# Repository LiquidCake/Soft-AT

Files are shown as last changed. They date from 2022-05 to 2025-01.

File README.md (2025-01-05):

# Soft-AT

This is an PC/AT (and PC/XT) compatible ISA board that provides some simple implementation of soft power controls (like we have on PC/ATX)  
Board should work on any PC with at least 8-bit ISA bus starting from original IBM-PC and up to Pentium machines  
Driver is tested on Windows 98 but probably may work on all Win9x  

### Functionality:
When properly installed & wired board allows power on/off for AT machine to mimic look&feel of power controls of ATX machine  
i.e. 
```
when PC is off - pressing (soft) power button starts it normally
when PC is on - pressing (soft) power button triggers windows shutdown and then poweroff after windows is unloaded (instead of instant hard poweroff of regular AT PSU)
when user clicks on shutdown in windows start menu - board receives signal and will turn power off after some delay (so windows will already be unloaded at that point)
```

**DISCLAIMER 1: this is a hobby project made by a person who is NOT and electronics engineer so it may be flawed in any possible way. It works though**

**DISCLAIMER 2: due to war i wasn't able to actually solder and test last revision of board, though it was just a minor tracks fix so should be fine**   

**For same reason i wasn't able to order and test board with actual 74LS series chips so it was tested only with 74LS's Soviet clones that i had easily available. They should be pretty much identical to original chips though**

**And this is also why there are no real pictures of assembled and properly installed board, only 3d renders**

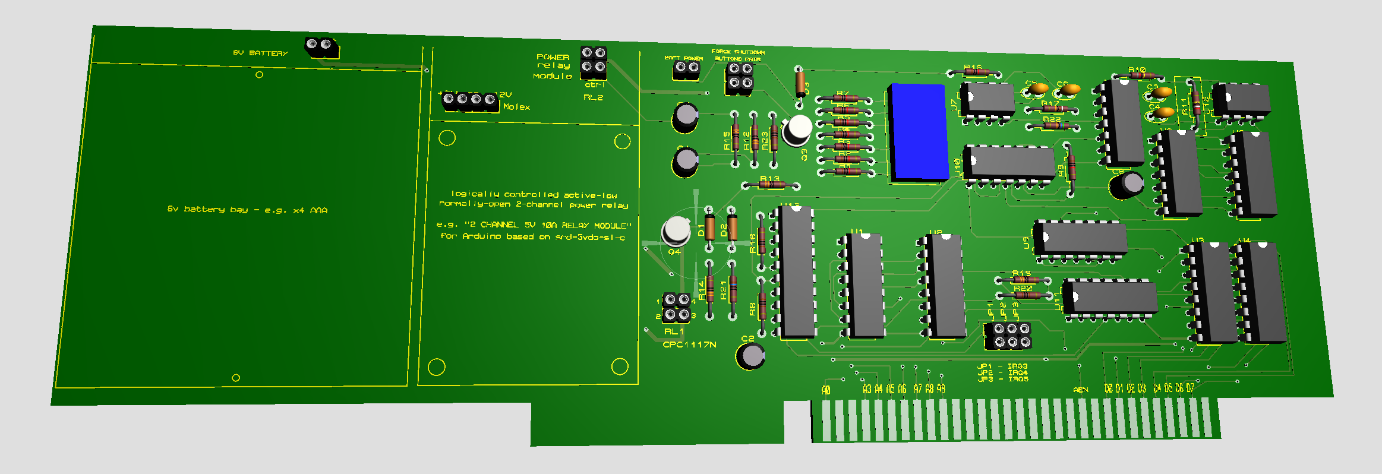
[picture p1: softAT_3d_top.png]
render


### Description:
Board was developed using `Proteus 8`, project files are provided as well as schematics and model screenshots  

In order to make board:  
- produce (order) PCB using provided `Gerber` files  
- mount/solder components from `components.txt` (the list is numerated list, same numbers on PCB silk and on schematics screenshot/Proteus project)  
*check component mount guide picture*
- insert board into ISA slot
- **!!!WARNING - high voltage here** disconnect your AT PSU from PC power switch (4 cables) and connect cables to large power relay RL2 that you've mounted on board  
DOUBLE CHECK:  
AT switch connects `white-to-blue`, `black-to-brown` so relay RL2 must do the same
- connect soft power button that will be used as PC power button  
(e.g. ideally you may put your AT motherboard and AT PSU into ATX PC case which has soft power button with proper header by default, though it is possible only if holes on board match ATX case board mount points)  
- probably connect reset button as force shutdown button `1` (see `force shutdown buttons` details below)
- connect one of PSU molex power connector to molex header on board (use smaller one, like one used for 3.5 floppies)  
- pick free IRQ and IO port address and set it on board phisically (check driver readme for more info on IRQ and IO port picking)  
	1. pick IRQ that is free on your PC and set it by board jumper `JP1/JP2/JP3` (e.g. `IRQ 3`)
	2. pick IO port that is free on your PC, convert its hex number to binary and set higher 7 bits by board DIP switch DSW1 (e.g. if using IO port address HEX `220` - convert to binary: `1000100000` and take 7 higher bits - `1000100`)
- adjust R11 so board timer ticks ~1sec at a time when counting for shutdown delay - e.g. set it to middle value and change a bit to find proper position empirically during device testing, having set driver shutdown delay to known value in seconds :)
- insert batteries into mounted battery bay (tested with `AA` batteries)  
make sure not to forget batteries inside bay for a long time because of possible leakage. Also for that reason it makes sense to use a very bottom ISA slot for vertical PC cases  
- install driver (.vxd and config) using install.bat (tested to work on Windows 98) - check readme for driver    

#####
Shutdown process wont be triggered after pressing soft power button if windows is in fullscreen dos mode (like dos game)  
(workaround to somehow make it work is possible, but would require both hardware and sofrware changes)

##### force shutdown buttons
There are 2 force shutdown buttons:  
`1` for shutting down operating PC (resets power relay RL2) - on PCB this button's contacts are top pair  
it would make sense to connect PC reset button as this one

`2` for disabling RL1 that initially opens pre-start battery power for RL2 - may be needed if PC didnt start after RL1 opened e.g. due wall power issues - on PCB this button's contacts are bottom pair  
it would make sense to connect some external button as this one, e.g. ideally mount such button on back pannel bar of ISA board

##### BTW
it is possible to use board as just external low-precision ISA timer that sends interrupt when done but this is not supported in current driver version since no real usage for that mode  
(if timeout value is sent to board using IO port with 0 at the end, e.g. 220 instead of 221 - board wont shutdown and will just send interrupt to CPU instead)

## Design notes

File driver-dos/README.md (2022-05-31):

## dos driver

This is an old dos "driver" for Soft-AT (actually its just an interrupt service routine, not a full format driver).  

*It should work but was not tested for some time*  

Should be working starting from 8088 CPU and dos 2.0  

settings like IO port, IRQ number, timer delay etc.s are hardcoded  

When `isr` is launched it loads itself into RAM and stays residential, waiting for interrupts. Once interrupt comes (from soft power button press) - driver sends shutdown signal to Soft-AT board and PC will be powered off after delay

`timer` binary may be used to send signal to Soft-AT board manually

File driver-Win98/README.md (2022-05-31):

# driver config file
driver reads first 11 bytes of **C:\\softat.cfg** file (Three 3-digit hex numbers split by semi-colon). Format is strict - allways 3 digits (start from 0 if needed e.g. 07f)

e.g. 
```
--file starts
221;003;005
--file ends
```

## numbers meaning: 

### first - IO port 
e.g. you can set generally-free IO port "221". Then 220 must be  selected on board DIP switch, 1 means least significant bit is set which triggers shutdown mode.  

Used IO port may conflict with other devices IO address space! Make sure it is not assigned to other device and make it "reserved" in Windows Device Manager, "Computer" properties.  

If this port is assigned in Windows to other device - some values will be eventually written to this port which will lead to random shutdown request to SoftAT board  

### second - IRQ number 
IRQ3-IRQ5 are supported by board. Choose IRQ that is less probale to be used by other devices in system and put its number in config file, then set corresponding jumper on board (JP1 is IRQ3, JP2 is IRQ4, JP3 is IRQ5).  

*Attention: IRQ you chose may conflict with one of COM/PARALLEL ports!*  

Suggested value is 003 (IRQ3) - commonly used by COM2 port which could be easily disabled in BIOS (and then IRQ 3 is free to use)  

Also, this IRQ must be "reserved" in Windows Device Manager (in "Computer" properties)  

### third - shutdown delay in seconds (counts seconds after system exit event is received)
Value is in 1 byte hex (0-FF), so 0-255sec  
e.g. "005" is 5sec

# notes:
Driver wont catch interrupts (soft power button presses) when running fullscreen DOS app (like dos game) - you need to exit that first

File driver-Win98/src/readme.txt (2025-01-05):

How to build on Windows 98:

1. install C compiler - e.g. Visual CPP 5.00.7022
2. install VToolsD (NuMega) - e.g. SoftICE Driver Suite 2.0.1
	it should add itself to env variables which are used in make file for includes
	in case of issues - try specifying full path to nmake.exe inside make.bat 
	and check autoexec.bat file, possibly adding compiler/IDE/other required lib folders to system PATH variable etc
3. compile by running make.bat - i had to copy driver src files to VC compiler root folder (where bin, lib etc resides)
4. output is a softat.vxd file, build is logged to res.txt file

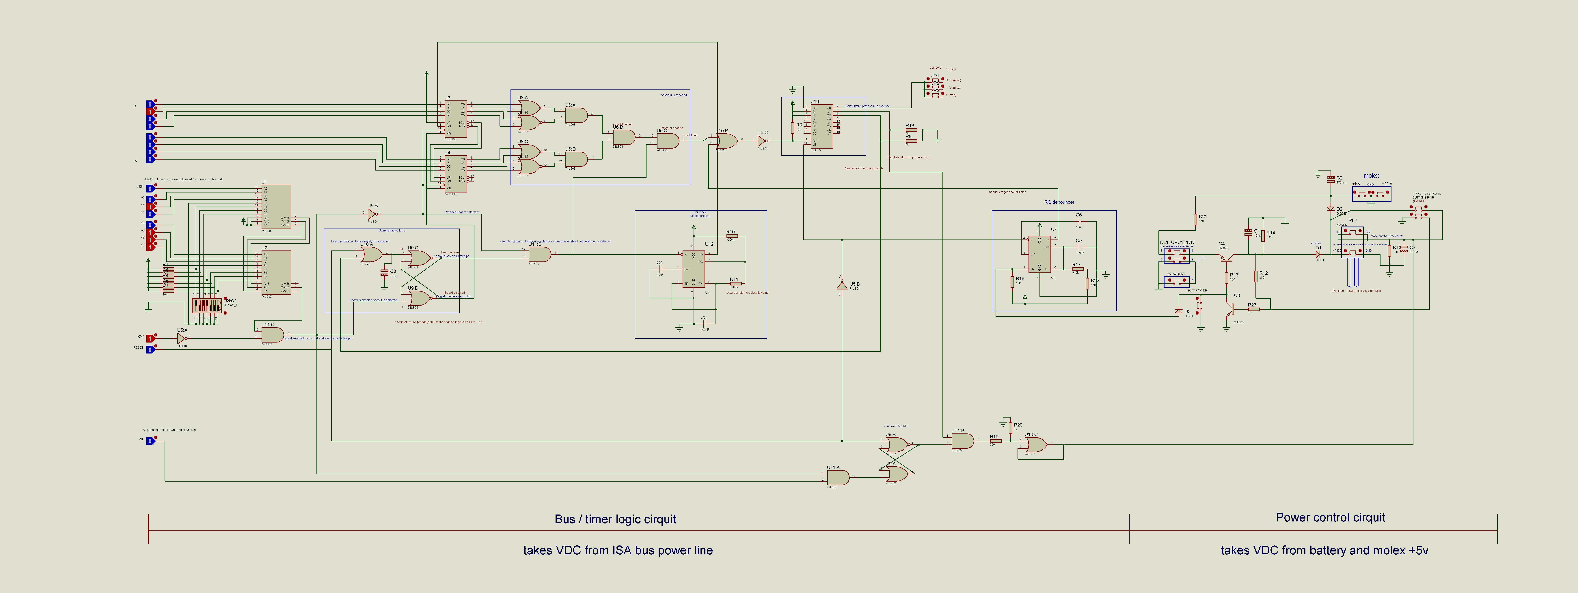
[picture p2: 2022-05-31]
softAT_schematics.png

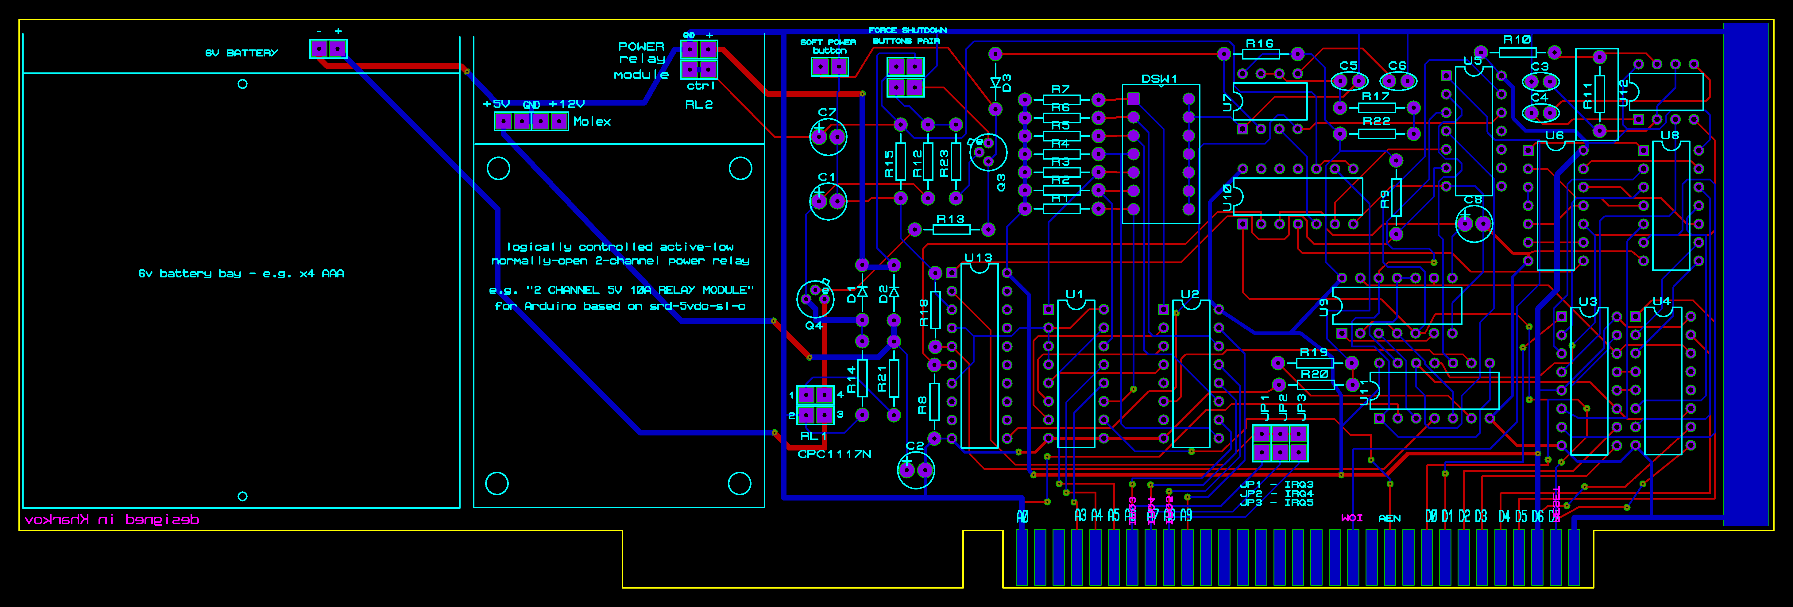
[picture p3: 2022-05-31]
softAT_layers.png

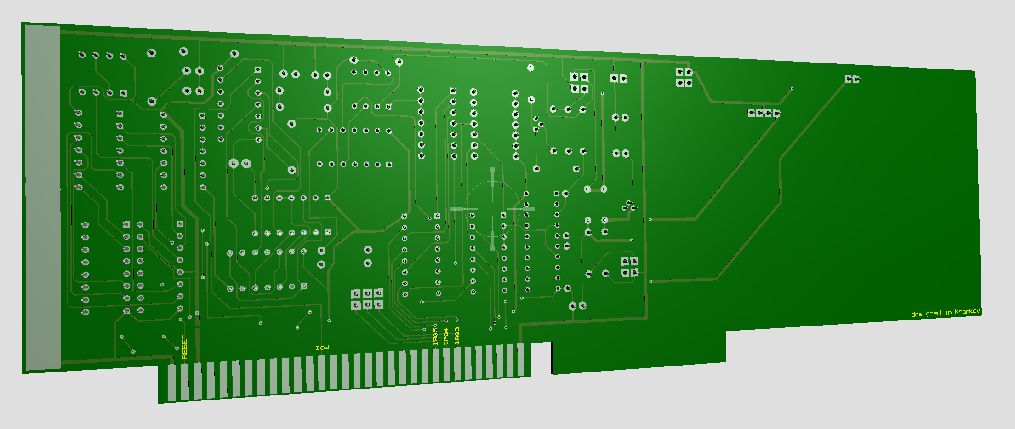
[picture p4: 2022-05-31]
softAT_3d_bot.png

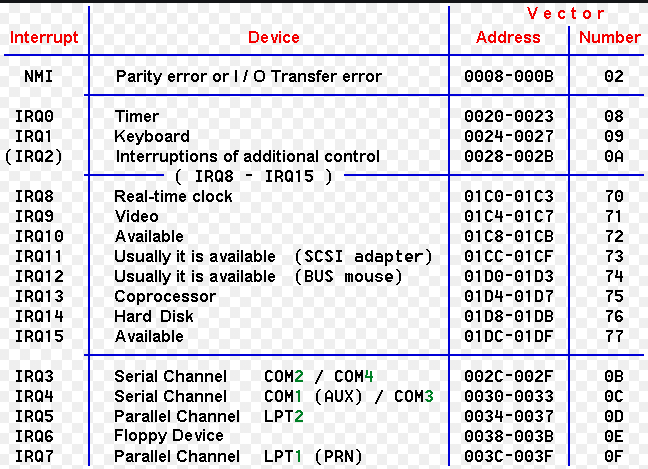
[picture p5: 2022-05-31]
driver-Win98/ibm-pc-irq-list.png

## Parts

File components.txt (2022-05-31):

# Capacitors						
Electrolyte						
3 C1,C7,C8 - 10mkf, 16v						
1 C2 - 470mkf, 16v						
						
Cyramics						
2 C3,C5 - 100nF						
2 C4,C6 - 10nF						

# Resistors all 0.125w, 1 adjustable (R11)						
9 R1,R2,R3,R4,R5,R6,R7,R9,R16 - 10k						
4 R8,R18,R20,R23 - 1k						
1 R10 - 8200k						
1 R11 - 2900k                     -- adjustable, to set timer tick interval
5 R12,R13,R14,R15,R19 - 330						
1 R17 - 910k						
1 R21 - 160						
1 R22 - 560k						

# Diodes						
2 D2,D3 - 1N4148						
1 D1 - 11DQ04 (Shotky)						

# Transistors						
1 Q3 - 2N2222						
1 Q4 - 2N2907A (2N2905)						

# ICs						
2 U1,U2 - 74LS85 (КР1533СП1)						
2 U3,U4 - 74LS193 (К555ИЕ7)						
1 U5 - 74LS04 (К555ЛН1)						
2 U6,U11 - 74LS08 (К555ЛИ1)						
2 U7,U12 - NE555 (КР1006ВИ1)						
2 U8,U9 - 74LS02 (К555ЛЕ1)						
1 U10 - 74LS32 (К555ЛЛ1)						
1 U13 - 74S373 (К555ИР22)						

# Pannels for ICs (Optional)						
2 - DIP8						
6 - DIP14						
4 - DIP16						
1 - DIP20						
(possibly 1 DIP4 pannel to solder CPC1117N on)						

# Relay						
1 RL1 - CPC1117N - or any normally-closed 5v relay capable of 150ma load current						
And if you use CPC1117N optoMOS relay and it is in SMD packaging like in my case - you will need to solder it somehow, e.g. i soldered i on top of DIP4 IC pannel						
						
1 RL2 - Power relay module - 5v logically controlled active-low normally-open 2-channel relay - e.g. active-low "2 CHANNEL 5V 10A RELAY MODULE" for Arduino based on SRD-05VDC-SL-C						
Load current depends on your PC consumption, generally 10A is good	

Suggest to mount by drilling holes (see them on silk) in PCB and using cable ties

# PCB pin header 2-pin pairs, e.g. PLS-40:						
3 - for irq jumpers						
1 - for battery block 6v						
1 - for soft power button						
2 - for power relay power/control						
2 - for force shutdown buttons						
(9 pairs / 18pins total)						

# Molex power connector						
1 - molex power connector - male header with spacing 2.54mm, e.g. NS25-W4K-SM WH-04R						

# DIP switch						
1 DSW1 - 7 contact pairs DIP switch						

# Battery						
1 - any 6v battery set capable to drive power relay which consumes ~100ma (with some peak at launch) for short period between power on and PSU is fully started
E.g. generic flat battery bay for 4 AA batteries

Suggest to mount by drilling holes (see them on silk) in PCB and using cable ties

# Buttons						
1 - push button for soft power, like "power sw" in ATX PC case (or just use soft power button of PC case if using ATX case)					
2 - push buttons for force-shutdown (or you may use PC reset button for upper button contacts pair + another custom button mounted on board back pannel for lower pair)					

# Cabels						
4 - short but thick power cables to connect PC's AT power supply to power relay load terminals						
Must have proper-size terminals attached to one end (same as on AT power supply button) - e.g. DEGSON K12-00AH						
Isolate carefully						
						
WARNING - high voltage is here, even when relay is open						
						
4 - short cables with female connectors (like NINIGI NSR-02) on both sides to connect power relay module 5v power / control pins with PCB header pins						
						
# Also:						
Battery bay,						
Soft power button,						
Force shutdown buttons pair -						
all must end with cables with female connectors to put on PCB header pins						
(4 pairs of wires + connectors)						

# Jumper						
1 - jumper for IRQ selection

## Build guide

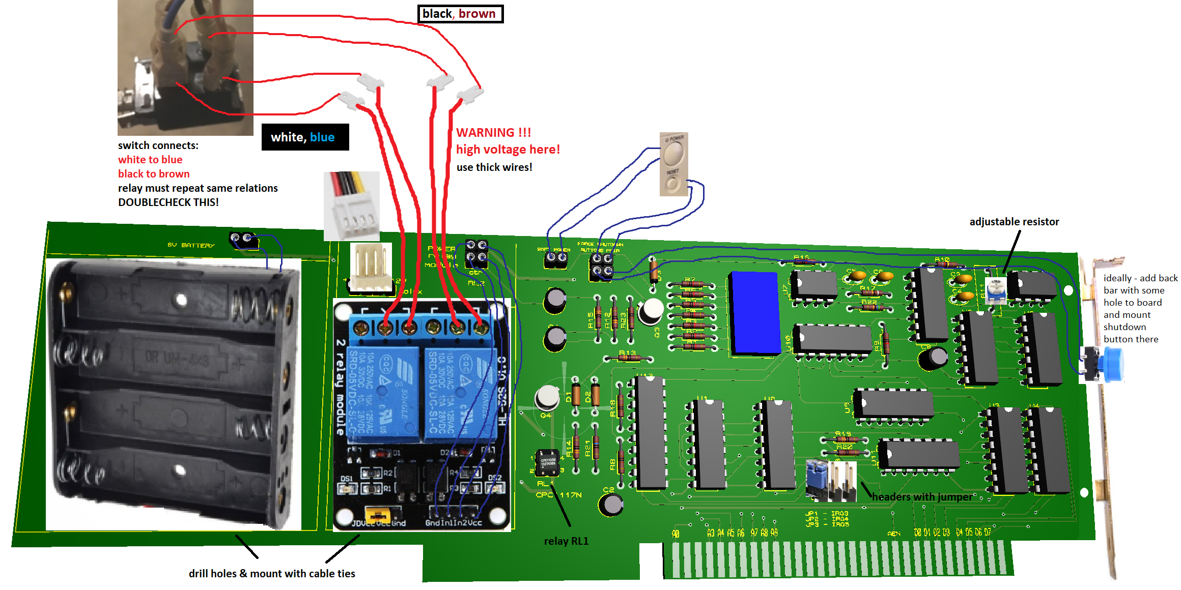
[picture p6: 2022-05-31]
softAT_components_mount_guide.png

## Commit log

2022-05-31 components list changed format
    [components.xlsx]
2022-05-31 added mount guide
